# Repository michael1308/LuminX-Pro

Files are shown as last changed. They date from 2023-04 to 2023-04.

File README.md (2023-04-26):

# LuminX-WLED
ESP32-based controller for individually addressable LED strips, compatible with WLED firmware.

# Features
-   ESP32-WROOM-32E
-   CH340E/G
-   USB C
-   Micro USB for power
-   2.1mm Barrel Jack w/ reversible polarity    
-   Screw Terminal power input
-   Current Measurement w/ INA219/INA180
-   5V Buck Converter
-   3.3V LDO
-   Microphone
-   IR Receiver
-   2x Digital out w/ Clock signal
-   Power Switching Relay
-   Temperature Sensor DS18B20
-   I2C Connector
-   ESP32 Debug Connector
-   Up to 10A

# Rev 1.0 (03.2023)
## Issues:
- Reverse Polarity Protection MOSFET reversed
- INA180 Resistor too large -> change to 10mOhm
- USBLC6 wrong footprint -> SOT-6

## Changes:
- Remove Micro USB
- Route Input Voltage directly to output
- Change reverse polarity protection to antiparallel diode (M7)
- Integrate PDM Microphone
- Better Integration for IR Sensor
- Better Integration for Temp Sensor
- 4 Output Channels
- Smaller Footprint
- Automotive or Glass fuse?
- Separate board for guitar -> LuminX ??

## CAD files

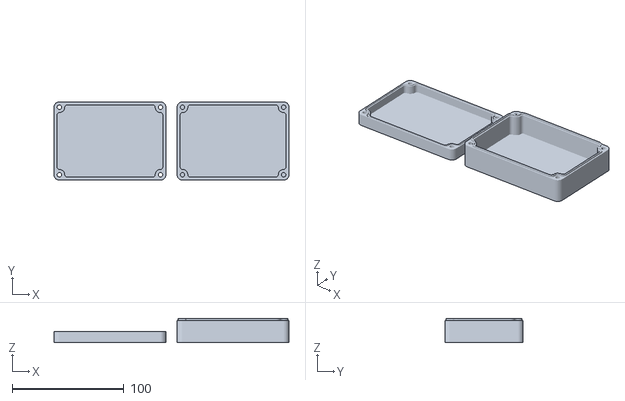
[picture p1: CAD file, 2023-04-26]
UltimateWaterproofCase_V6.1_noholes.stl
210.0 x 70.0 x 21.7

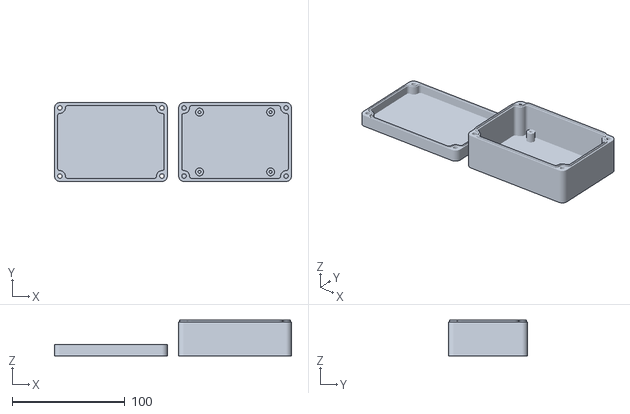
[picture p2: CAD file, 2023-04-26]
WLED_Case.stl
210.0 x 70.0 x 31.7

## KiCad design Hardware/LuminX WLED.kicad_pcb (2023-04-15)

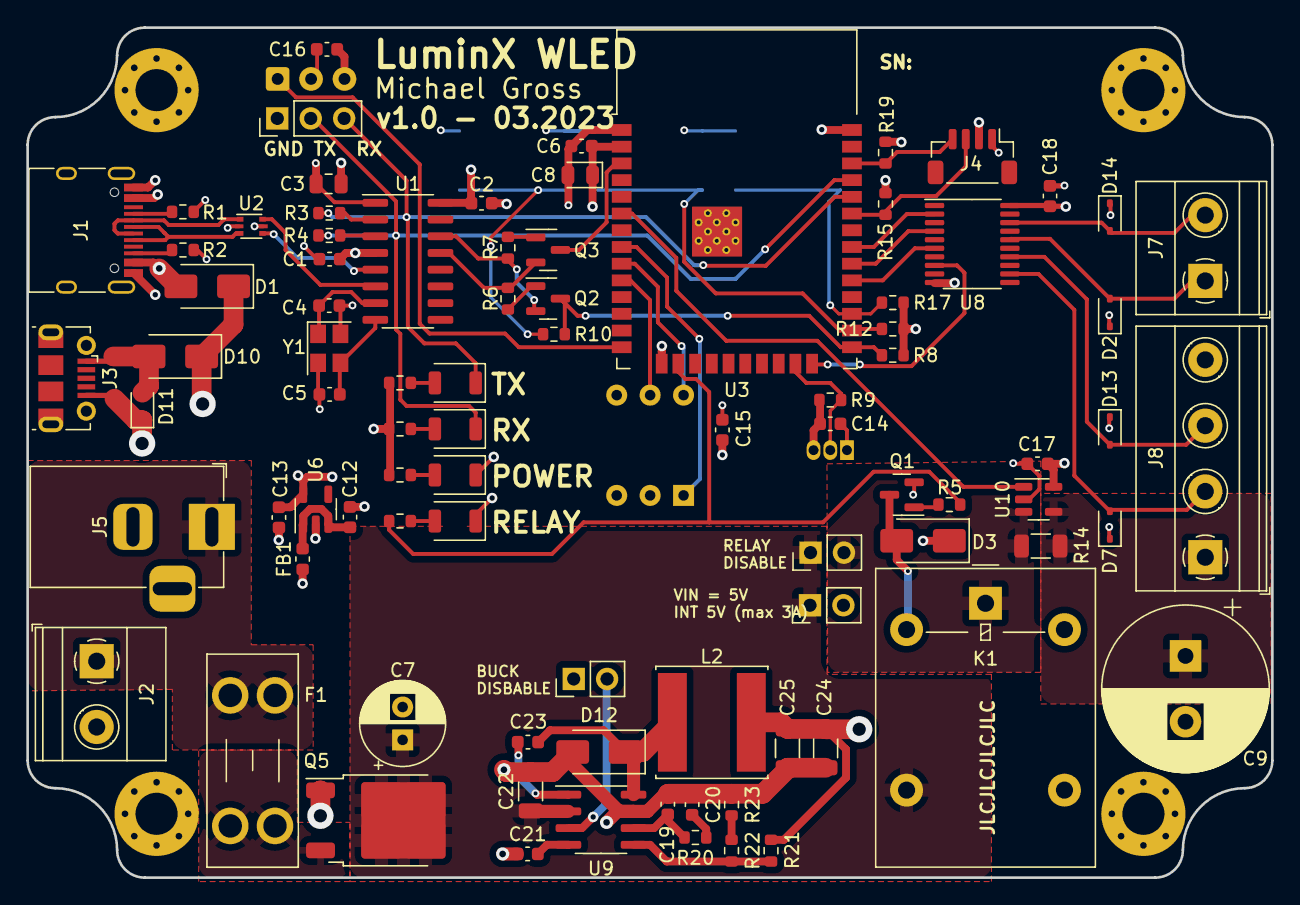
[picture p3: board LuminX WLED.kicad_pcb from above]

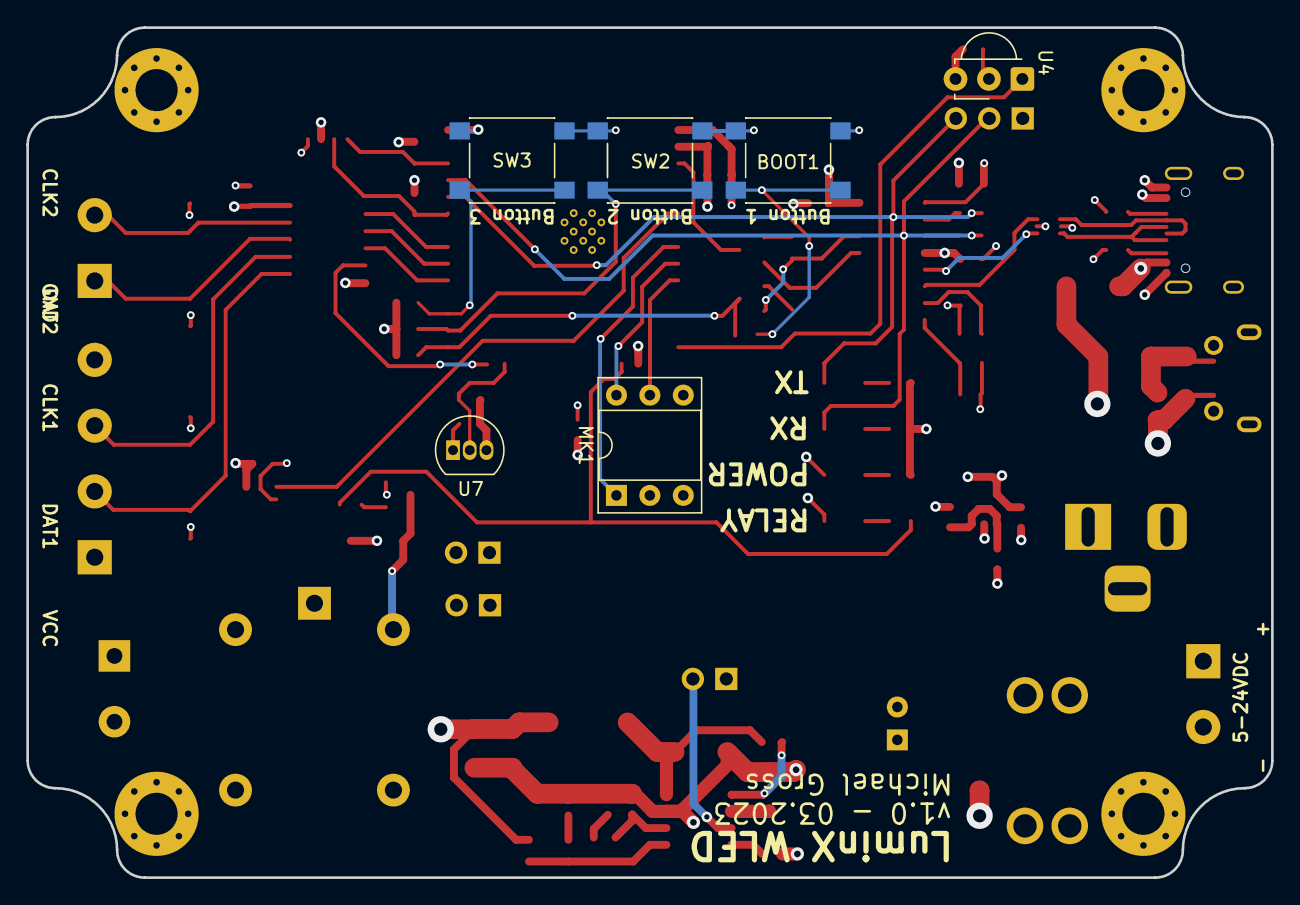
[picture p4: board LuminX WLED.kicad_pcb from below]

Board: 4 copper layers, 94.6 x 64.6 mm, 96 parts (6 on the bottom side), 63 nets.

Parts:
BOOT1: SW_Push; SW_SPST_PTS645
C1, C2, C6, C14, C15, C16, C17, C18, C23: 100n; C_0603_1608Metric
C3: 10u; C_0805_2012Metric
C4, C5: 30p; C_0603_1608Metric
C7: 100u/35V; CP_Radial_D6.3mm_P2.50mm
C8: 10u; D_0805_2012Metric
C9: 1000u; CP_Radial_D12.5mm_P5.00mm
C12, C13: 1u; C_0603_1608Metric
C19: 10p; C_0603_1608Metric
C20: 1n; C_0603_1608Metric
C21: 8n2; C_0603_1608Metric
C22: 10u; C_1206_3216Metric
C24, C25: 22u; C_1206_3216Metric
D1, D10: SS34; D_SMA
D2, D7, D11, D13, D14: SD05; D_SOD-323
D3: US1G; D_SMA
D4: YELLOW; LED_1206_3216Metric_ReverseMount_Hole1.8x2.4mm
D5, D6: GREEN; LED_1206_3216Metric_ReverseMount_Hole1.8x2.4mm
D9: AMBER; LED_1206_3216Metric_ReverseMount_Hole1.8x2.4mm
D12: SS54; D_SMA
F1: 10A; Fuseholder_Blade_Mini_Keystone_3568
FB1: 100R; L_0603_1608Metric
H1, H2, H3, H4: MountingHole; MountingHole_3.2mm_M3_Pad_Via
J1: USB_C_Receptacle_USB2.0; USB_C_Receptacle_HRO_TYPE-C-31-M-12
J2, J7: 5mm Screw Terminal; TerminalBlock_Phoenix_MKDS-1,5-2_1x02_P5.00mm_Horizontal
J3: USB_B_Micro; USB_Micro-B_Molex-105017-0001
J4: Conn_01x04_Pin; JST_SH_BM04B-SRSS-TB_1x04-1MP_P1.00mm_Vertical
J5: Barrel_Jack_Switch; BarrelJack_Horizontal
J8: 5mm Screw Terminal; TerminalBlock_Phoenix_MKDS-1,5-4_1x04_P5.00mm_Horizontal
J9: Conn_01x03_Pin; PinHeader_1x03_P2.54mm_Vertical
JP1, JP2, JP3: Jumper_2_Open; PinHeader_1x02_P2.54mm_Vertical
K1: G5LE-1; Relay_SPDT_Omron-G5LE-1
L2: 10u/3A; L_Sunlord_SWPA8040S
MK1: INMP441; DIP-6_W7.62mm_Socket
Q1, Q2, Q3: BC847; SOT-23
Q5: IRF5305; TO-252-2
R1, R2: 5k1; R_0603_1608Metric
R3, R4, R10: 470R; R_0603_1608Metric
R5: 220R; R_0603_1608Metric
R6, R7, R8, R9, R12, R17, R21: 10k; R_0603_1608Metric
R11, R13, R16, R18: 1k; R_0603_1608Metric
R14: 0.1R; R_1206_3216Metric
R15, R19: 4k7; R_0603_1608Metric
R20: 33k; R_0603_1608Metric
R22: 1k2; R_0603_1608Metric
R23: 680; R_0603_1608Metric
SW2, SW3: SW_Push; SW_SPST_PTS645
U1: CH340G; SOIC-16_3.9x9.9mm_P1.27mm
U2: USBLC6-2P6; SOT-666
U3: ESP32-WROOM-32D
U4: TSOP382xx; Vishay_MINICAST-3Pin
U6: AP2112K-3.3; SOT-23-5
U7: DS18B20; TO-92_Inline
U8: 74AHCT244; TSSOP-20_4.4x6.5mm_P0.65mm
U9: TPS54332; SOIC-8_3.9x4.9mm_P1.27mm
U10: INA180A1; SOT-23-5
Y1: 12MHz; Crystal_SMD_3225-4Pin_3.2x2.5mm

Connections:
+3V3: C1.1, C2.1, C3.1, C6.1, C8.1, C13.1, C14.1, C15.1, C16.1, C17.1, J4.2, MK1.2 (VDD), R8.1, R9.1, R11.1, R12.1, R13.1, R15.1, R16.1, R17.1, R19.1, U1.4 (V3), U1.16 (VCC), U3.2 (VDD), U4.3 (Vs), U6.5 (VOUT), U7.3 (V_{DD}), U10.5 (V+)
+5V: C18.1, C24.1, C25.1, D1.1 (K), D3.1 (K), D10.1 (K), FB1.1, JP3.2 (B), K1.5, L2.2, R21.2, U8.20 (VCC)
/ESP32+CH340/CH340_XI: C4.1, U1.7 (XI), Y1.1
/ESP32+CH340/CH340_XO: C5.1, U1.8 (XO), Y1.3
/ESP32+CH340/nDTR: Q3.2 (E), R6.1, U1.13 (~DTR)
/ESP32+CH340/nRTS: Q2.2 (E), R7.1, U1.14 (~RTS)
/Power+USB/D+: J1.A6 (D+), J1.B6 (D+), U2.3 (I/O2)
/Power+USB/D-: J1.A7 (D-), J1.B7 (D-), U2.1 (I/O1)
/Power+USB/INA180_IN: JP2.2 (B), K1.1, R14.1, U10.3 (+)
/Power+USB/VBUS_MICROUSB: D10.2 (A), D11.2 (A2), J3.1 (VBUS)
/Power+USB/VBUS_USBC: D1.2 (A), J1.A4 (VBUS), J1.A9 (VBUS), J1.B4 (VBUS), J1.B9 (VBUS), U2.5 (VBUS)
/Power+USB/VIN_RAW: F1.1, J2.1, J5.1
/Power+USB/VIN_RPP: F1.2, Q5.3 (S)
CLK1: D13.2 (A2), J8.3, U8.14 (1Y2)
CLK1_3V3: U3.29 (IO5), U8.6 (1A2)
CLK2: D14.2 (A2), J7.2, U8.18 (1Y0)
CLK2_3V3: U3.31 (IO19), U8.2 (1A0)
DAT1: D7.2 (A2), J8.2, U8.12 (1Y3)
DAT1_3V3: U3.24 (IO2), U8.8 (1A3)
DAT2: D2.2 (A2), J7.1, U8.16 (1Y1)
DAT2_3V3: U3.30 (IO18), U8.4 (1A1)
EN: Q3.3 (C), U3.3 (EN)
ESP32_RX: D5.1 (K), J9.3, R3.2, U3.34 (RXD0/IO3)
ESP32_TX: D4.1 (K), J9.2, R4.2, U3.35 (TXD0/IO1)
GND: BOOT1.2, C1.2, C2.2, C3.2, C4.2, C5.2, C6.2, C7.2, C8.2, C9.2, C12.2, C13.2, C14.2, C15.2, C16.2, C17.2, C18.2, C19.2, C20.2, C21.2, C22.2, C24.2, C25.2, D2.1 (A1), D6.1 (K), D7.1 (A1), D9.1 (K), D11.1 (A1), D12.2 (A), D13.1 (A1), D14.1 (A1), H1.1, H2.1, H3.1, H4.1, J1.A1 (GND), J1.A12 (GND), J1.B1 (GND), J1.B12 (GND), J2.2, J3.5 (GND), J4.1, J5.2, J8.4, J9.1, JP1.1 (A), MK1.3 (GND), MK1.4 (L/R), Q1.2 (E), Q5.1 (G), R1.2, R2.2, R23.1, SW2.2, SW3.2, U1.1 (GND), U2.2 (GND), U3.1 (GND), U3.15 (GND), U3.38 (GND), U3.39 (GND), U4.2 (GND), U6.2 (GND), U7.1 (GND), U8.10 (GND), U9.7 (GND), U10.2 (GND), Y1.2, Y1.4
IO0: Q2.3 (C), R8.2, R10.1, U3.25 (IO0)
IR_CTRL: U3.14 (IO12), U4.1 (OUT)
unnamed: C12.1, FB1.2, U6.1 (VIN), U6.3 (EN)
unnamed: BOOT1.1, R10.2
unnamed: C20.1, R20.1
unnamed: D3.2 (A), K1.2, Q1.3 (C)
unnamed: D4.2 (A), R11.2
unnamed: D5.2 (A), R13.2
unnamed: D6.2 (A), R16.2
unnamed: D9.2 (A), R18.2
unnamed: C23.2, D12.1 (K), L2.1, U9.8 (PH)
unnamed: J1.A5 (CC1), R1.1
unnamed: J1.B5 (CC2), R2.1
unnamed: JP1.2 (B), U9.3 (EN)
unnamed: Q1.1 (B), R5.2
unnamed: Q2.1 (B), R6.2
unnamed: Q3.1 (B), R7.2
unnamed: R22.1, R23.2
unnamed: R4.1, U1.3 (RXD)
unnamed: R3.1, U1.2 (TXD)
unnamed: C23.1, U9.1 (BOOT)
unnamed: C19.1, R20.2, U9.6 (COMP)
unnamed: C21.1, U9.4 (SS)
unnamed: R21.1, R22.2, U9.5 (VSENSE)
RELAY_CTRL: R5.1, R18.1, U3.16 (IO13)
SCK: MK1.6 (SCK), U3.9 (IO33)
SCL: J4.4, R19.2, U3.36 (IO22)
SD: MK1.1 (SD), U3.8 (IO32)
SDA: J4.3, R15.2, U3.33 (IO21)
SW2: R12.2, SW2.1, U3.26 (IO4)
SW3: R17.2, SW3.1, U3.27 (IO16)
TEMP: R9.2, U3.23 (IO15), U7.2 (DQ)
USB_D+: U1.5 (UD+), U2.4 (I/O2)
USB_D-: U1.6 (UD-), U2.6 (I/O1)
VIN: C7.1, C22.1, JP2.1 (A), JP3.1 (A), K1.3, Q5.2 (D), U9.2 (VIN)
VOUT_LED: C9.1, J8.1, R14.2, U10.4 (-)
V_SENSE: U3.6 (IO34), U10.1
WS: MK1.5 (WS), U3.10 (IO25)
